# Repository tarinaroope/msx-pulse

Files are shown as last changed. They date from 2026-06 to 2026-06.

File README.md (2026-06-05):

# msx-pulse

A diagnostic cartridge for MSX computers. Very much a work in progress. This is at
proof-of-concept stage. It boots, it reads the bus, it tells you things, but it's a
long way from a finished product. I'm building it partly because I wanted an "is this
MSX dead, and if so why" tool, and partly to learn, so expect rough edges.

## What it does today

Plug it into the cartridge slot and it sits there passively. It doesn't drive the bus,
so it's safe to leave in while the MSX powers up on its own. While it watches, it
reports on a small OLED:

- the +5V, +12V and −12V rails
- whether the 3.58 MHz clock is alive and roughly the right frequency
- the state of /RESET
- what the address and data lines are doing, including bits that look stuck or are
  never driven

It can also pulse /RESET and follow the early boot sequence to see how far the machine
gets. There's a USB serial log too if you want the detail on a host.

That's already enough to tell, say, a dead clock apart from dead RAM without pulling
the machine apart. I'm still working out the full list of faults it can sensibly
diagnose and a lot of that will come from pointing it at actually-broken machines and
seeing what shows up.

## What's next

The next goal is to have the cartridge *serve* a diagnostic ROM to the MSX and act as
the boot ROM itself and run Z80 test code on the machine's own CPU, the way the Dead
Test cart does. The firmware already has the groundwork for this (it can emulate a ROM
on the bus), but turning that into a proper guided test sequence is the next chunk of
work. The passive monitoring above is the part that somewhat works.

## Hardware

Fair warning: I'm a software person, not a hardware engineer, and this board is one of
the first things I've designed. It's a quick first cut to get *something* I could test
firmware against, and it shows. There's a KiCad project in [`hardware/`](hardware/)
(schematics, PCB, gerbers) and a parts list in [`docs/BOM.csv`](docs/BOM.csv) — read
them as "what I actually had made", not "the right way to do this".

The brain is a bare RP2354B (the QFN-80 part, 48 GPIO, 2 MB internal flash) wired onto
the cartridge edge connector and powered from the slot. The current board puts 74LVC245
level shifters on just about every bus line. Having lived with it, I think that's
overkill... the address and control inputs could most likely get by with plain series
resistors and no shifters. The data lines are the exception: those are bidirectional
and actually get driven, so keeping real level shifting there still makes sense, mostly
for protection.

Things I'd like to change in the next board revision:

- drop the level shifters on the address/control inputs, keep them on D0–D7
- shrink the PCB to fit an actual MSX cartridge shell (it's oversized right now)
- swap the ADC protection diodes as I miscalculated the zeners, seems it works even better without.
- a bigger power-on-reset cap for a more reliable cold boot
- a normal 2.54 mm SWD header (plus a UART header which I omitted) instead of the fine-pitch one I used

## Building

You'll need the Arm GNU toolchain (`arm-none-eabi`), the Raspberry Pi Pico SDK, and
sjasmplus for the Z80 side.

```sh
export PICO_SDK_PATH=/path/to/pico-sdk
cmake -S . -B build -DPICO_TOOLCHAIN_PATH=/path/to/arm-none-eabi/bin
cmake --build build -j
```

Out comes:

- `build/src/firmware/msxdoc.uf2` — the firmware
- `build/diag.rom` — the Z80 test ROM, assembled and baked into the firmware for you (not served) 

## Flashing

Hold BOOTSEL, plug into USB, and drop the `.uf2` onto the drive that appears. Or, with
picotool:

```sh
picotool load -x build/src/firmware/msxdoc.uf2
```

Or via swd.

## Layout

```
src/rom/        Z80 test ROM (sjasmplus)
src/firmware/   RP2354B firmware (pico-sdk, C + PIO)
hardware/       KiCad schematics, PCB, gerbers
docs/           bill of materials
```

## License

MIT — see [LICENSE](LICENSE).

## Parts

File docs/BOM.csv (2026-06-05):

Designator | Qty | Value | Package | Description | MPN / Note | LCSC Part #
U2 | 1 | RP2354B | QFN-80 | MCU — ROM emulator, bus monitor, output controller | Raspberry Pi RP2354B
U1 | 1 | AP2112K-3.3 | SOT-23-5 | LDO 600mA, 3.3V fixed output | Diodes AP2112K-3.3TRG1
U3, U4, U5, U6 | 4 | 74LVC245 | SOIC-20 | Octal bus transceiver, 5V tolerant, 3.3V VCC | TI SN74LVC245ADWR or equiv
L1 | 1 | 3.3µH, Abracon AOTA-B201610S3R3-101-T | 0806 (2016 metric) | SMPS inductor — polarity dot CRITICAL; use this exact part | Abracon AOTA-B201610S3R3-101-T
D1 | 1 | BAT54C | SOT-23 | Dual Schottky, common cathode — power OR circuit | Nexperia BAT54C,215
D2, D3, D4 | 3 | BZX84-C3V3 | SOT-23 | 3.3V Zener — ADC input overvoltage clamp. [SPIN-2: replace with PESD3V3L1BA SOT-23, see KNOWN_RISKS L7] | Nexperia BZX84-C3V3,235 or equiv
Q1 | 1 | 2N7002 | SOT-23 | N-MOSFET — MSX /RESET drive | Nexperia 2N7002,235 or equiv
Y1 | 1 | 12MHz crystal | 3225 SMD | Crystal — USB and PIO timing; ABM8-272-T3 recommended | Abracon ABM8-272-T3 (recommended) or equiv 12MHz 10pF 50Ω ESR
R20, R22 | 2 | 27Ω | 0603 5% | USB DP/DM series termination — place close to MCU
R3, R14, R24 | 3 | 33Ω | 0603 5% | 2N7002 gate damper (R3) + VREG_AVDD filter (R14) + ADC_AVDD filter (R24)
R4, R23 | 2 | 330Ω | 0603 5% | LED current limiter (R4), /WAIT series protection (R23)
R9, R15, R18, R19, R21 | 5 | 1kΩ | 0603 5% | BOOTSEL isolation, crystal XOUT damping, ADC series protection
R1, R2 | 2 | 10kΩ | 0603 5% | RUN pin pull-up (R1) + 74LVC245 /OE pull-up (R2)
R5, R6 | 2 | 4.7kΩ | 0603 5% | I2C SDA + SCL pull-ups
R7, R8 | 2 | 5.1kΩ | 0603 5% | USB-C CC1 + CC2 pull-downs
R10, R11, R13, R16 | 4 | 10kΩ | 0603 1% | ADC voltage dividers (1% required for rail measurement accuracy)
R12 | 1 | 33kΩ | 0603 1% | +12V rail divider (high side)
R17 | 1 | 82kΩ | 0603 1% | −12V bridge divider (low side)
C4, C5 | 2 | 15pF C0G/NP0 | 0603 | Crystal load caps — C0G/NP0 mandatory
C1 | 1 | 1µF X5R 6.3V | 0603 | LDO VIN bypass
C2 | 1 | 10µF X5R 6.3V | 0603 | LDO output bulk cap
C24 | 1 | 1µF X5R 6.3V | 0402 | ADC_AVDD filter cap
C18, C19, C20 | 3 | 4.7µF X5R 6.3V | 0402 | VREG: AVDD filter cap (C18), VIN bypass (C19), DVDD output (C20)
C3, C6 | 2 | 100nF X7R 10V | 0603 | Decoupling: LDO local (C3), reset RC (C6)
C7, C8, C9, C10, C11, C12, C13, C14, C15, C16, C21, C22, C23 | 13 | 100nF X7R 10V | 0402 | MCU decoupling: IOVDD (×8, C7–C14), QSPI/USB (×2, C15–C16), DVDD (×3, C21–C23)
J3 | 1 | GCT USB4085 | mid-mount SMD | USB-C receptacle — firmware update + serial log | GCT USB4085-GF-A
J4 | 1 | SWD 3-pin header | 1.27mm pitch SMD | SWD debug: SWDIO / SWDCLK / GND
J2 | 1 | 4-pin 2.54mm header | through-hole | OLED mounting header (SDA, SCL, GND, 3.3V)
SW1, SW2, SW3, SW4 | 4 | 6×6mm SMD tactile | SMD | Buttons: RESET (SW1), UP (SW2), DOWN (SW3), SELECT (SW4) | C&K PTS645SK43SMTR92 LFS or equiv
LED1 | 1 | Green LED | 0603 | Firmware-driven status LED (GP38 via R4). Not a passive power indicator.

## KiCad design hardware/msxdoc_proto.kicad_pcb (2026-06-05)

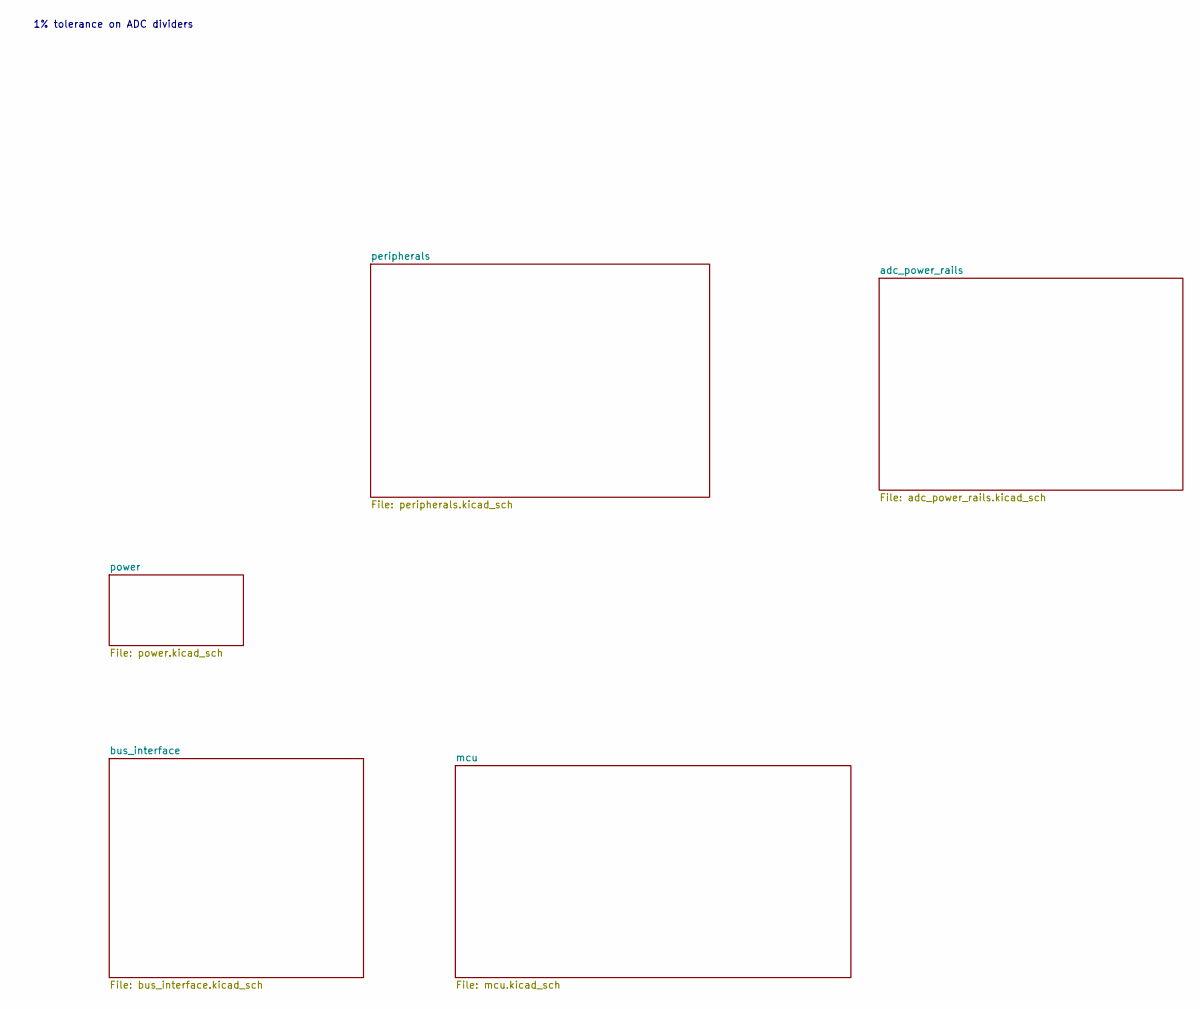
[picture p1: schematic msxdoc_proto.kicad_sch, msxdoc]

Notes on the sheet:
1% tolerance on ADC dividers

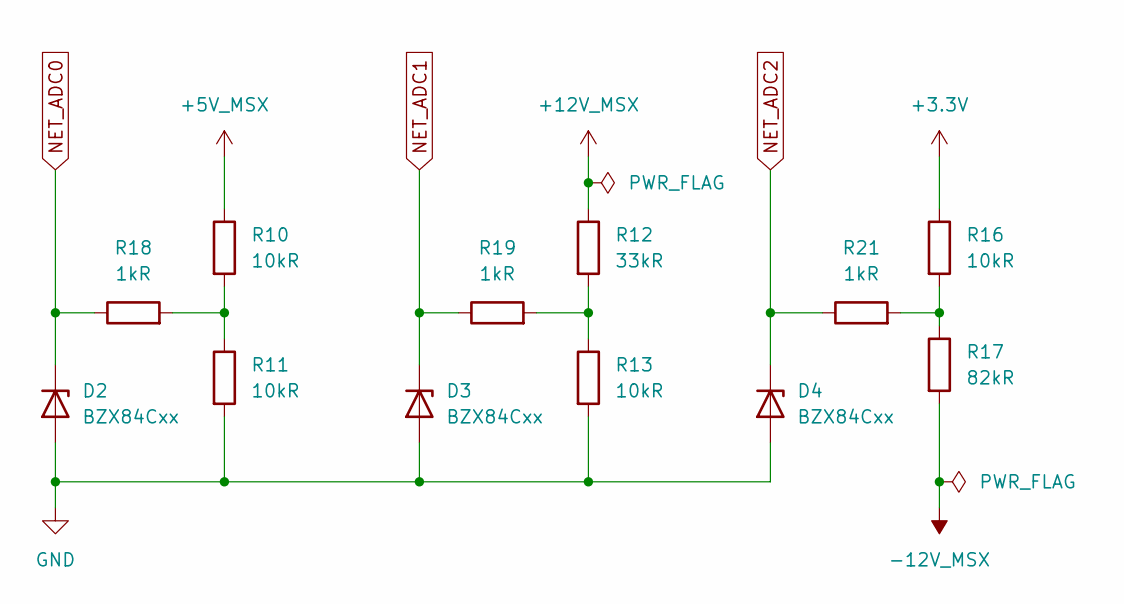
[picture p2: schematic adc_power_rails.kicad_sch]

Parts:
D2, D3, D4: BZX84Cxx; SOT-23
R10, R11, R13, R16: 10kR; R_0603_1608Metric
R12: 33kR; R_0603_1608Metric
R17: 82kR; R_0603_1608Metric
R18, R19, R21: 1kR; R_0603_1608Metric

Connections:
+3.3V: R16.1; also elsewhere on the board
+5V_MSX: R10.1; also elsewhere on the board
+12V_MSX: R12.1; also elsewhere on the board
-12V_MSX: R17.2; also elsewhere on the board
GND: D2.1 (A), D3.1 (A), D4.1 (A), R11.2, R13.2; also elsewhere on the board
NET_ADC0: D2.3 (K), R18.1; also elsewhere on the board
NET_ADC1: D3.3 (K), R19.1; also elsewhere on the board
NET_ADC2: D4.3 (K), R21.1; also elsewhere on the board
unnamed: R10.2, R11.1, R18.2
unnamed: R12.2, R13.1, R19.2
unnamed: R16.2, R17.1, R21.2

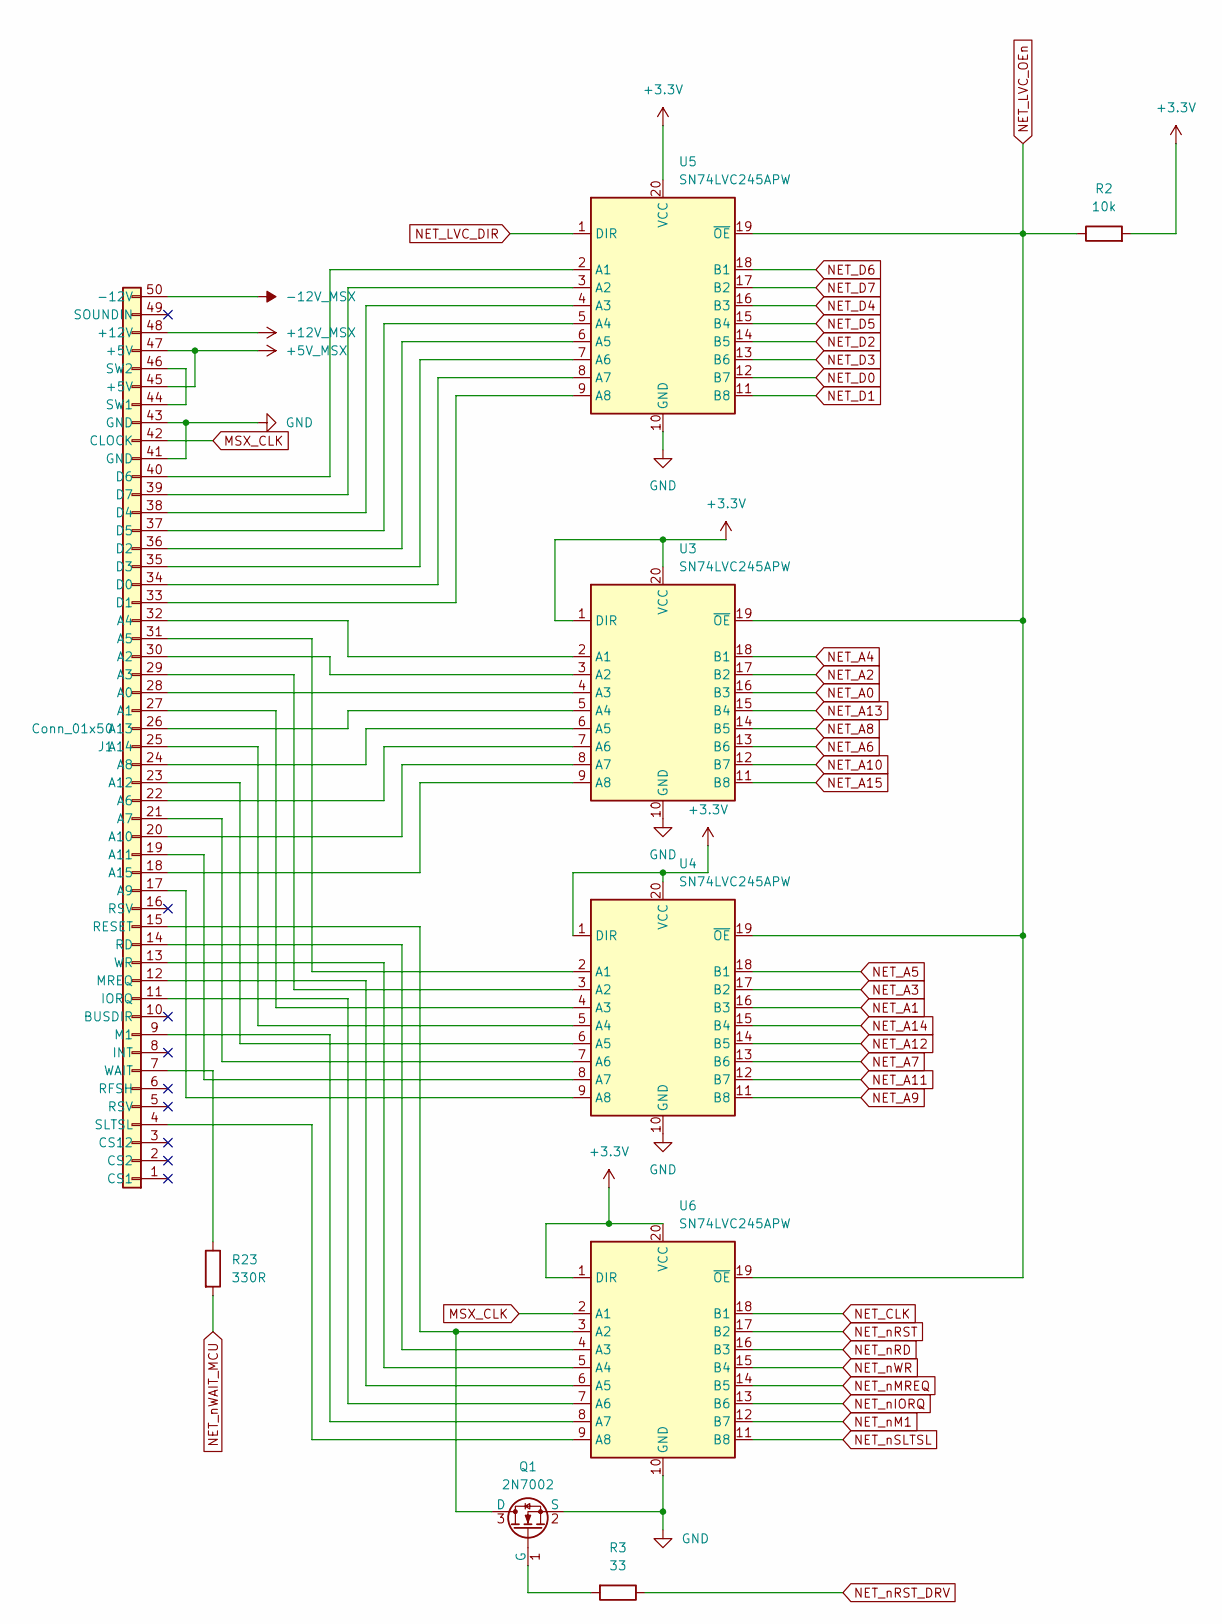
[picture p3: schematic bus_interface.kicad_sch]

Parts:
J1: Conn_01x50; MSX-EDGE
Q1: 2N7002; SOT-23; LCSC C81445
R2: 10k; R_0603_1608Metric
R3: 33; R_0603_1608Metric
R23: 330R; R_0603_1608Metric
U3, U4, U5, U6: SN74LVC245APW; TSSOP-20_4.4x6.5mm_P0.65mm; LCSC C7848

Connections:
+3.3V: R2.2, U3.1 (DIR), U3.20 (VCC), U4.1 (DIR), U4.20 (VCC), U5.20 (VCC), U6.1 (DIR), U6.20 (VCC); also elsewhere on the board
+5V_MSX: J1.45 (+5V), J1.47 (+5V); also elsewhere on the board
+12V_MSX: J1.48 (+12V); also elsewhere on the board
-12V_MSX: J1.50 (-12V); also elsewhere on the board
GND: J1.41 (GND), J1.43 (GND), Q1.2 (S), U3.10 (GND), U4.10 (GND), U5.10 (GND), U6.10 (GND); also elsewhere on the board
MSX_CLK: J1.42 (CLOCK), U6.2 (A1)
NET_A0: U3.16 (B3); also elsewhere on the board
NET_A1: U4.16 (B3); also elsewhere on the board
NET_A2: U3.17 (B2); also elsewhere on the board
NET_A3: U4.17 (B2); also elsewhere on the board
NET_A4: U3.18 (B1); also elsewhere on the board
NET_A5: U4.18 (B1); also elsewhere on the board
NET_A6: U3.13 (B6); also elsewhere on the board
NET_A7: U4.13 (B6); also elsewhere on the board
NET_A8: U3.14 (B5); also elsewhere on the board
NET_A9: U4.11 (B8); also elsewhere on the board
NET_A10: U3.12 (B7); also elsewhere on the board
NET_A11: U4.12 (B7); also elsewhere on the board
NET_A12: U4.14 (B5); also elsewhere on the board
NET_A13: U3.15 (B4); also elsewhere on the board
NET_A14: U4.15 (B4); also elsewhere on the board
NET_A15: U3.11 (B8); also elsewhere on the board
NET_CLK: U6.18 (B1); also elsewhere on the board
NET_D0: U5.12 (B7); also elsewhere on the board
NET_D1: U5.11 (B8); also elsewhere on the board
NET_D2: U5.14 (B5); also elsewhere on the board
NET_D3: U5.13 (B6); also elsewhere on the board
NET_D4: U5.16 (B3); also elsewhere on the board
NET_D5: U5.15 (B4); also elsewhere on the board
NET_D6: U5.18 (B1); also elsewhere on the board
NET_D7: U5.17 (B2); also elsewhere on the board
NET_LVC_DIR: U5.1 (DIR); also elsewhere on the board
NET_LVC_OEn: R2.1, U3.19 (~OE), U4.19 (~OE), U5.19 (~OE), U6.19 (~OE); also elsewhere on the board
NET_nIORQ: U6.13 (B6); also elsewhere on the board
NET_nM1: U6.12 (B7); also elsewhere on the board
NET_nMREQ: U6.14 (B5); also elsewhere on the board
NET_nRD: U6.16 (B3); also elsewhere on the board
NET_nRST: U6.17 (B2); also elsewhere on the board
NET_nRST_DRV: R3.1; also elsewhere on the board
NET_nSLTSL: U6.11 (B8); also elsewhere on the board
NET_nWAIT_MCU: R23.2; also elsewhere on the board
NET_nWR: U6.15 (B4); also elsewhere on the board
unnamed: J1.28 (A0), U3.4 (A3)
unnamed: J1.27 (A1), U4.4 (A3)
unnamed: J1.30 (A2), U3.3 (A2)
unnamed: J1.29 (A3), U4.3 (A2)
unnamed: J1.32 (A4), U3.2 (A1)
unnamed: J1.31 (A5), U4.2 (A1)
unnamed: J1.22 (A6), U3.7 (A6)
unnamed: J1.21 (A7), U4.7 (A6)
unnamed: J1.24 (A8), U3.6 (A5)
unnamed: J1.17 (A9), U4.9 (A8)
unnamed: J1.20 (A10), U3.8 (A7)
unnamed: J1.19 (A11), U4.8 (A7)
unnamed: J1.23 (A12), U4.6 (A5)
unnamed: J1.26 (A13), U3.5 (A4)
unnamed: J1.25 (A14), U4.5 (A4)
unnamed: J1.18 (A15), U3.9 (A8)
unnamed: J1.34 (D0), U5.8 (A7)
unnamed: J1.33 (D1), U5.9 (A8)
unnamed: J1.36 (D2), U5.6 (A5)
unnamed: J1.35 (D3), U5.7 (A6)
unnamed: J1.38 (D4), U5.4 (A3)
unnamed: J1.37 (D5), U5.5 (A4)
unnamed: J1.40 (D6), U5.2 (A1)
unnamed: J1.39 (D7), U5.3 (A2)
unnamed: J1.11 (IORQ), U6.7 (A6)
unnamed: J1.9 (M1), U6.8 (A7)
unnamed: J1.12 (MREQ), U6.6 (A5)
unnamed: J1.14 (RD), U6.4 (A3)
unnamed: J1.15 (RESET), Q1.3 (D), U6.3 (A2)
unnamed: J1.4 (SLTSL), U6.9 (A8)
unnamed: J1.44 (SW1), J1.46 (SW2)
unnamed: J1.7 (WAIT), R23.1
unnamed: J1.13 (WR), U6.5 (A4)
unnamed: Q1.1 (G), R3.2

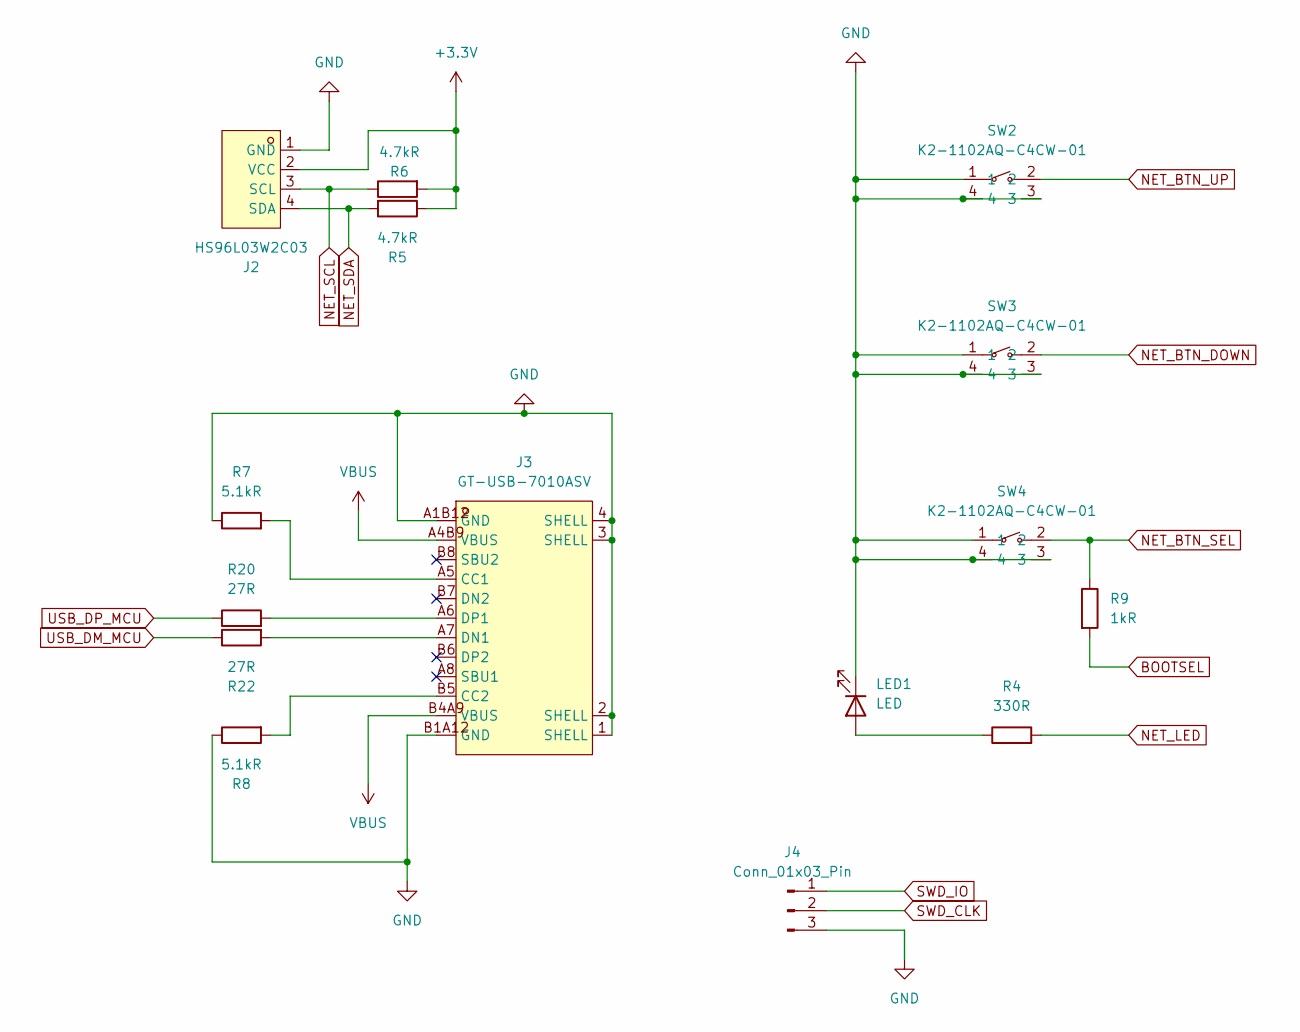
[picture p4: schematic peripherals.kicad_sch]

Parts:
J2: HS96L03W2C03; OLED-TH_L27.8-W27.2-P2.54_C9900033791; MPN HS96L03W2C03; LCSC Part C5248080
J3: GT-USB-7010ASV; USB-C-SMD_G-SWITCH_GT-USB-7010ASV; MPN GT-USB-7010ASV; LCSC Part C2988369
J4: Conn_01x03_Pin; PinHeader_1x03_P2.54mm_Vertical
LED1: LED; LED_0603_1608Metric
R4: 330R; R_0603_1608Metric
R5, R6: 4.7kR; R_0603_1608Metric
R7, R8: 5.1kR; R_0603_1608Metric
R9: 1kR; R_0603_1608Metric
R20, R22: 27R; R_0603_1608Metric
SW2, SW3, SW4: K2-1102AQ-C4CW-01; SW-TH_K2-1102AQ-C4CW-01; MPN K2-1102AQ-C4CW-01; LCSC Part C127680

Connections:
+3.3V: J2.2 (VCC), R5.1, R6.2; also elsewhere on the board
BOOTSEL: R9.2; also elsewhere on the board
GND: J2.1 (GND), J3.1 (SHELL), J3.2 (SHELL), J3.3 (SHELL), J3.4 (SHELL), J3.A1B12 (GND), J3.B1A12 (GND), J4.3, LED1.1 (K), R7.1, R8.1, SW2.1, SW2.3, SW2.4, SW3.1, SW3.3, SW3.4, SW4.1, SW4.3, SW4.4; also elsewhere on the board
NET_BTN_DOWN: SW3.2; also elsewhere on the board
NET_BTN_SEL: R9.1, SW4.2; also elsewhere on the board
NET_BTN_UP: SW2.2; also elsewhere on the board
NET_LED: R4.2; also elsewhere on the board
NET_SCL: J2.3 (SCL), R6.1; also elsewhere on the board
NET_SDA: J2.4 (SDA), R5.2; also elsewhere on the board
unnamed: J3.A5 (CC1), R7.2
unnamed: J3.B5 (CC2), R8.2
unnamed: J3.A7 (DN1), R22.2
unnamed: J3.A6 (DP1), R20.2
unnamed: LED1.2 (A), R4.1
SWD_CLK: J4.2; also elsewhere on the board
SWD_IO: J4.1; also elsewhere on the board
USB_DM_MCU: R22.1; also elsewhere on the board
USB_DP_MCU: R20.1; also elsewhere on the board
VBUS: J3.A4B9 (VBUS), J3.B4A9 (VBUS); also elsewhere on the board

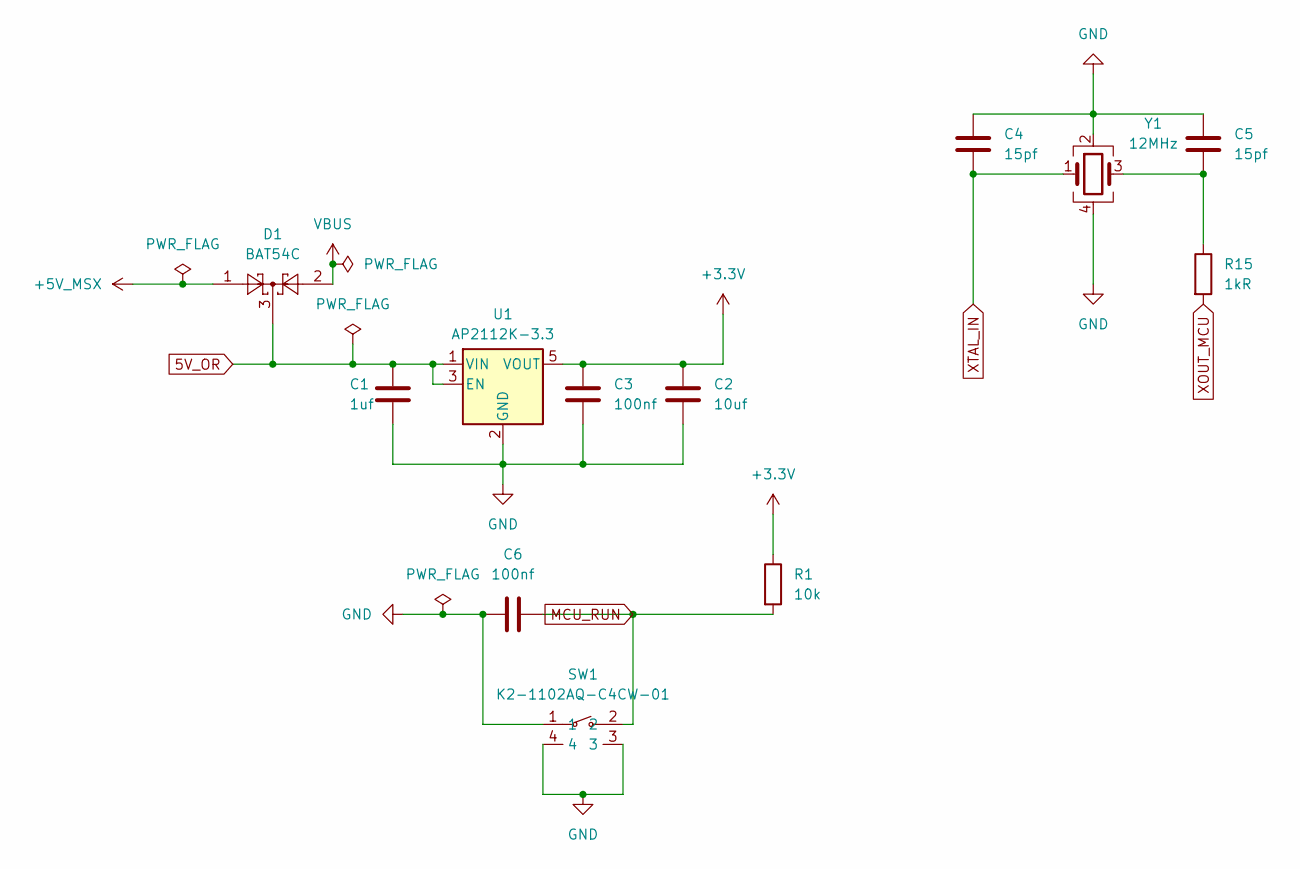
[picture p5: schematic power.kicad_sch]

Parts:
C1: 1uf; C_0603_1608Metric
C2: 10uf; C_0603_1608Metric
C3, C6: 100nf; C_0603_1608Metric
C4, C5: 15pf; C_0603_1608Metric
D1: BAT54C; SOT-23; LCSC C37704
R1: 10k; R_0603_1608Metric
R15: 1kR; R_0603_1608Metric
SW1: K2-1102AQ-C4CW-01; SW-TH_K2-1102AQ-C4CW-01; MPN K2-1102AQ-C4CW-01; LCSC Part C127680
U1: AP2112K-3.3; SOT-23-5; LCSC C23380830
Y1: 12MHz; Crystal_SMD_3225-4Pin_3.2x2.5mm; LCSC part C20625731

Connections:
5V_OR: C1.1, D1.3, U1.1 (VIN), U1.3 (EN)
+3.3V: C2.1, C3.1, R1.1, U1.5 (VOUT); also elsewhere on the board
+5V_MSX: D1.1; also elsewhere on the board
GND: C1.2, C2.2, C3.2, C4.1, C5.1, C6.1, SW1.1, SW1.3, SW1.4, U1.2 (GND), Y1.2, Y1.4; also elsewhere on the board
MCU_RUN: C6.2, R1.2, SW1.2; also elsewhere on the board
unnamed: C5.2, R15.1, Y1.3
VBUS: D1.2; also elsewhere on the board
XOUT_MCU: R15.2; also elsewhere on the board
XTAL_IN: C4.2, Y1.1; also elsewhere on the board

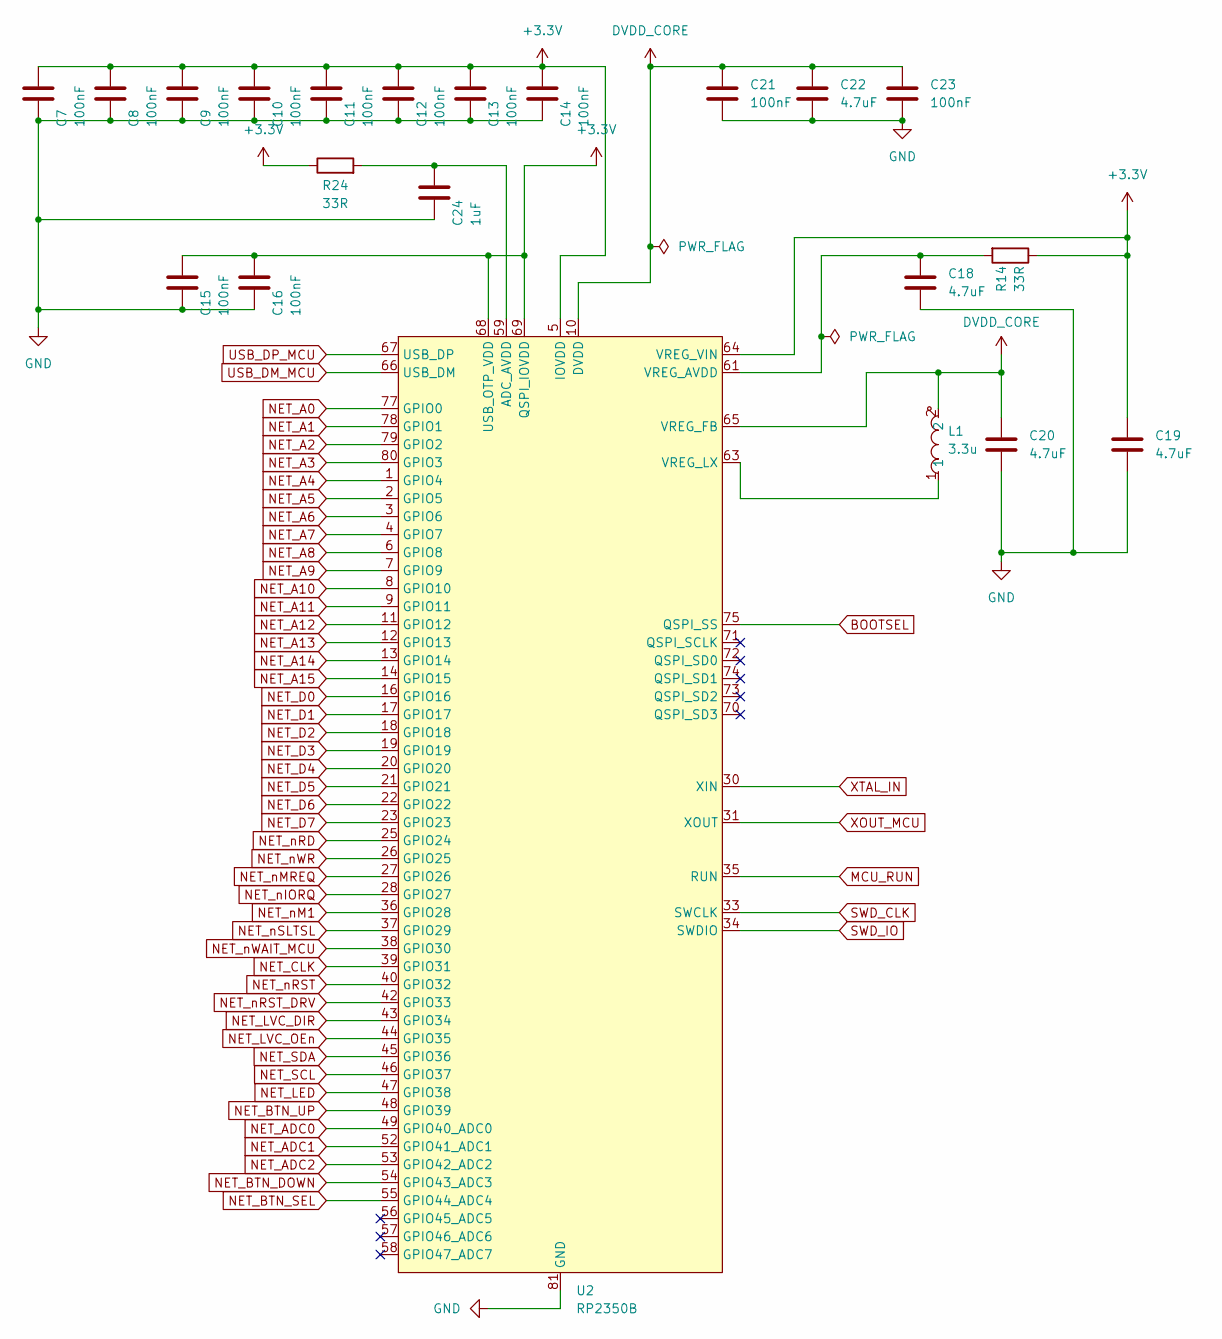
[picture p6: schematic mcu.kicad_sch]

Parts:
C7, C8, C9, C10, C11, C12, C13, C14, C15, C16, C21, C23: 100nF; C_0402_1005Metric
C18, C19, C20, C22: 4.7uF; C_0402_1005Metric
C24: 1uF; C_0402_1005Metric
L1: 3.3u; IND-SMD_L2.0-W1.6_AOTA-B201610S3R3-101-T; MPN AOTA-B201610S3R3-101-T; LCSC Part C42411119
R14, R24: 33R; R_0603_1608Metric
U2: RP2350B; QFN-80-1EP_10x10mm_P0.4mm_EP3.4x3.4mm_ThermalVias

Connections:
+3.3V: C7.1, C8.1, C9.1, C10.1, C11.1, C12.1, C13.1, C14.1, C15.1, C16.1, C19.1, R14.1, R24.1, U2.5 (IOVDD), U2.15 (IOVDD), U2.24 (IOVDD), U2.29 (IOVDD), U2.41 (IOVDD), U2.50 (IOVDD), U2.60 (IOVDD), U2.64 (VREG_VIN), U2.68 (USB_OTP_VDD), U2.69 (QSPI_IOVDD), U2.76 (IOVDD); also elsewhere on the board
BOOTSEL: U2.75 (QSPI_SS); also elsewhere on the board
DVDD_CORE: C20.1, C21.1, C22.1, C23.1, L1.2, U2.10 (DVDD), U2.32 (DVDD), U2.51 (DVDD), U2.65 (VREG_FB)
GND: C7.2, C8.2, C9.2, C10.2, C11.2, C12.2, C13.2, C14.2, C15.2, C16.2, C18.2, C19.2, C20.2, C21.2, C22.2, C23.2, C24.2, U2.62 (VREG_PGND), U2.81 (GND); also elsewhere on the board
MCU_RUN: U2.35 (RUN); also elsewhere on the board
NET_A0: U2.77 (GPIO0); also elsewhere on the board
NET_A1: U2.78 (GPIO1); also elsewhere on the board
NET_A2: U2.79 (GPIO2); also elsewhere on the board
NET_A3: U2.80 (GPIO3); also elsewhere on the board
NET_A4: U2.1 (GPIO4); also elsewhere on the board
NET_A5: U2.2 (GPIO5); also elsewhere on the board
NET_A6: U2.3 (GPIO6); also elsewhere on the board
NET_A7: U2.4 (GPIO7); also elsewhere on the board
NET_A8: U2.6 (GPIO8); also elsewhere on the board
NET_A9: U2.7 (GPIO9); also elsewhere on the board
NET_A10: U2.8 (GPIO10); also elsewhere on the board
NET_A11: U2.9 (GPIO11); also elsewhere on the board
NET_A12: U2.11 (GPIO12); also elsewhere on the board
NET_A13: U2.12 (GPIO13); also elsewhere on the board
NET_A14: U2.13 (GPIO14); also elsewhere on the board
NET_A15: U2.14 (GPIO15); also elsewhere on the board
NET_ADC0: U2.49 (GPIO40_ADC0); also elsewhere on the board
NET_ADC1: U2.52 (GPIO41_ADC1); also elsewhere on the board
NET_ADC2: U2.53 (GPIO42_ADC2); also elsewhere on the board
NET_BTN_DOWN: U2.54 (GPIO43_ADC3); also elsewhere on the board
NET_BTN_SEL: U2.55 (GPIO44_ADC4); also elsewhere on the board
NET_BTN_UP: U2.48 (GPIO39); also elsewhere on the board
NET_CLK: U2.39 (GPIO31); also elsewhere on the board
NET_D0: U2.16 (GPIO16); also elsewhere on the board
NET_D1: U2.17 (GPIO17); also elsewhere on the board
NET_D2: U2.18 (GPIO18); also elsewhere on the board
NET_D3: U2.19 (GPIO19); also elsewhere on the board
NET_D4: U2.20 (GPIO20); also elsewhere on the board
NET_D5: U2.21 (GPIO21); also elsewhere on the board
NET_D6: U2.22 (GPIO22); also elsewhere on the board
NET_D7: U2.23 (GPIO23); also elsewhere on the board
NET_LED: U2.47 (GPIO38); also elsewhere on the board
NET_LVC_DIR: U2.43 (GPIO34); also elsewhere on the board
NET_LVC_OEn: U2.44 (GPIO35); also elsewhere on the board
NET_SCL: U2.46 (GPIO37); also elsewhere on the board
NET_SDA: U2.45 (GPIO36); also elsewhere on the board
NET_nIORQ: U2.28 (GPIO27); also elsewhere on the board
NET_nM1: U2.36 (GPIO28); also elsewhere on the board
NET_nMREQ: U2.27 (GPIO26); also elsewhere on the board
NET_nRD: U2.25 (GPIO24); also elsewhere on the board
NET_nRST: U2.40 (GPIO32); also elsewhere on the board
NET_nRST_DRV: U2.42 (GPIO33); also elsewhere on the board
NET_nSLTSL: U2.37 (GPIO29); also elsewhere on the board
NET_nWAIT_MCU: U2.38 (GPIO30); also elsewhere on the board
NET_nWR: U2.26 (GPIO25); also elsewhere on the board
unnamed: C24.1, R24.2, U2.59 (ADC_AVDD)
unnamed: C18.1, R14.2, U2.61 (VREG_AVDD)
unnamed: L1.1, U2.63 (VREG_LX)
SWD_CLK: U2.33 (SWCLK); also elsewhere on the board
SWD_IO: U2.34 (SWDIO); also elsewhere on the board
USB_DM_MCU: U2.66 (USB_DM); also elsewhere on the board
USB_DP_MCU: U2.67 (USB_DP); also elsewhere on the board
XOUT_MCU: U2.31 (XOUT); also elsewhere on the board
XTAL_IN: U2.30 (XIN); also elsewhere on the board

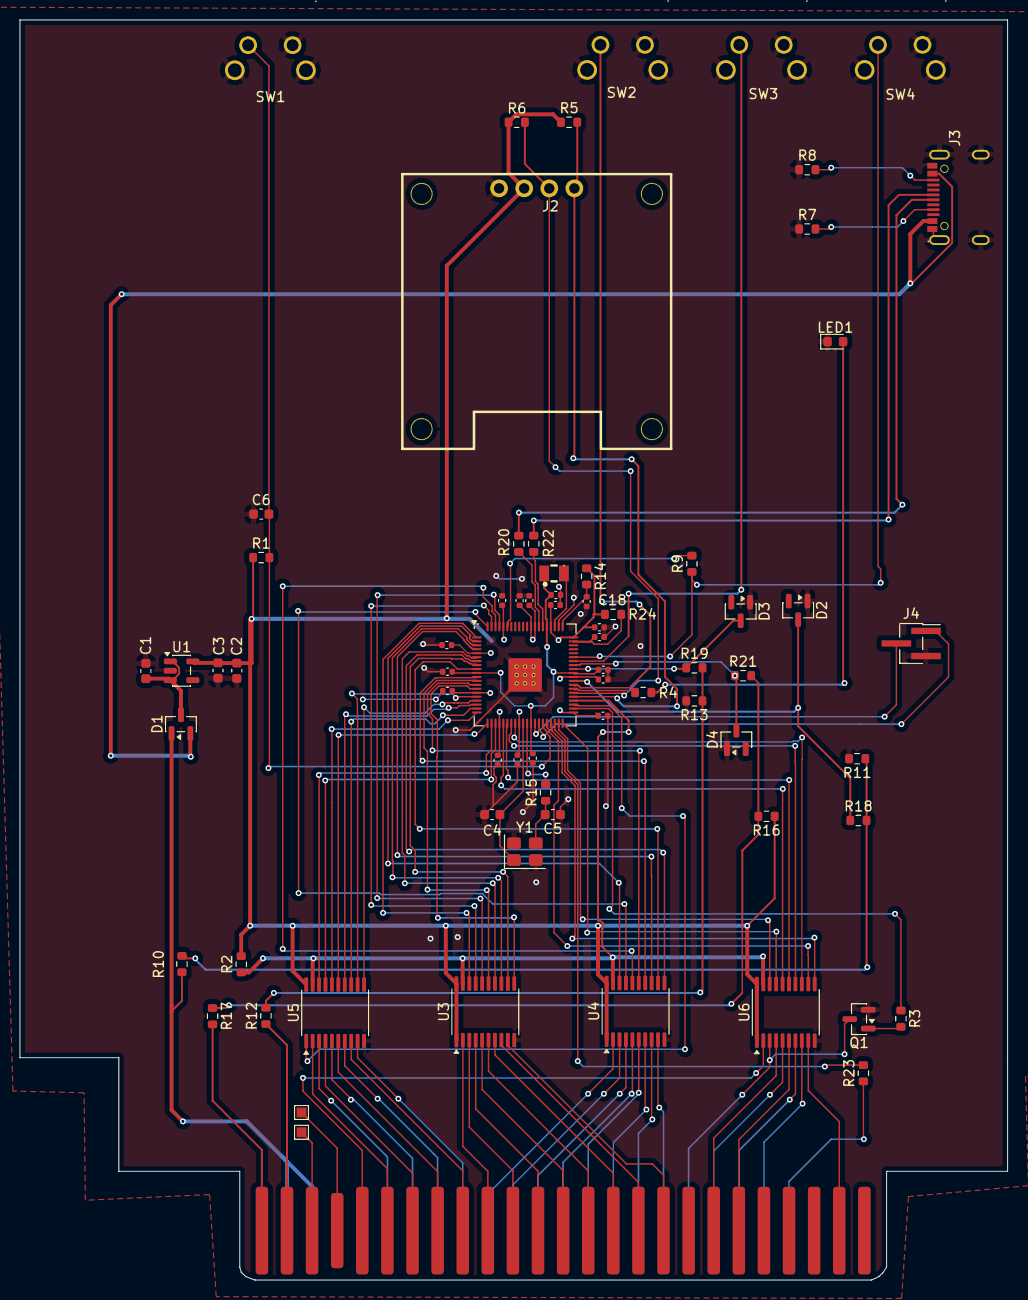
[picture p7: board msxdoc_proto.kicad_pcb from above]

Board: 2 copper layers, 99.9 x 127.5 mm, 69 parts (0 on the bottom side), 108 nets.

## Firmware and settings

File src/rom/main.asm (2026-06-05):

    DEVICE NOSLOT64K
    ORG $4000

VDP_DATA    EQU $98
VDP_CTRL    EQU $99

PSG_ADDR    EQU $A0     ; write: latch register number
PSG_DATA    EQU $A1     ; write: write to latched register
PSG_READ    EQU $A2     ; read:  read from latched register

SLOT_REG    EQU $A8     ; primary slot select register
KB_COLRD    EQU $A9     ; PPI port B: keyboard column read
KB_ROWSEL   EQU $AA     ; PPI port C: keyboard row select (bits 3:0)

VRAM_NAME   EQU $0000       ; Screen 0 name table (40×24)
VRAM_PTRN   EQU $0800       ; Screen 0 pattern table (256 × 8 bytes)
COLS        EQU 40

RAM_START   EQU $C000       ; first byte of guaranteed MSX1 main RAM
RAM_END     EQU $FFFF       ; last byte

VRAM_TEST_START EQU $1000   ; first VRAM byte safe to test (avoids display area)
VRAM_TEST_END   EQU $3FFF   ; last VRAM byte (12 KB)

    DB  "AB"            ; $4000  cartridge ID
    DW  Init            ; $4002  INIT entry point
    DW  0               ; $4004  STATEMENT (unused)
    DW  0               ; $4006  DEVICE    (unused)
    DW  0               ; $4008  TEXT      (unused)
    DS  6, 0            ; $400A  reserved

Init:
    DI
    ld  sp, $FFFF       ; stack at top of RAM before any testing

    ; Init the VDP directly instead of via BIOS CHGMOD ($005F), so the
    ; diagnostic still shows output if the main BIOS ROM is dead. Sets up
    ; Screen 0 (text, 40x24), loads the font into the pattern table, clears
    ; the name table.
    in  a, (VDP_CTRL)   ; sync VDP byte flip-flop before writes

    ld  a, $00          ; R0: M3=0, no external video, no hsync int
    ld  e, 0
    call VDP_WriteReg
    ld  a, $D0          ; R1: display ON, M1=1 (Text Mode), no frame int
    ld  e, 1
    call VDP_WriteReg
    ld  a, $00          ; R2: name table base = VRAM $0000
    ld  e, 2
    call VDP_WriteReg
    ld  a, $01          ; R4: pattern table base = VRAM $0800
    ld  e, 4
    call VDP_WriteReg
    ld  a, $F4          ; R7: text = white ($F), bg = dark blue ($4)
    ld  e, 7
    call VDP_WriteReg

    call LoadFont       ; copy 96 printable-ASCII glyphs to VRAM $0900+

    call ClearScreen

    ld  hl, Str_Banner
    ld  de, VRAM_NAME + COLS * 1 + 11   ; row 1, centred
    call PrintStr

    ; CPU register / ALU test
    ld  hl, Str_CpuLabel
    ld  de, VRAM_NAME + COLS * 3 + 2
    call PrintStr

    call TestCPU
    ld  hl, Str_Pass
    or  a
    jr  z, .cpu_done
    ld  hl, Str_Fail
.cpu_done:
    ld  de, VRAM_NAME + COLS * 3 + 22
    call PrintStr

    ; RAM test ($C000-$FFFF, 16 KB).
    ; The test loops use only LD/INC/DEC/JP, no CALL, so the stack at $FFFF
    ; stays untouched while testing. CALLs before and after are fine. If the
    ; stack bytes ($FFFD-$FFFE) are themselves bad, a post-test CALL crashes —
    ; accepted, since the fault was already detected.
    ld  hl, Str_RamLabel
    ld  de, VRAM_NAME + COLS * 5 + 2
    call PrintStr

    ; Pass 1: write $AA
    ld  d, $AA
    ld  hl, RAM_START
    ld  bc, RAM_END - RAM_START + 1
.ram_w1:
    ld  (hl), $AA
    inc hl
    dec bc
    ld  a, b
    or  c
    jr  nz, .ram_w1

    ; Pass 1: verify $AA
    ld  hl, RAM_START
    ld  bc, RAM_END - RAM_START + 1
.ram_r1:
    ld  a, (hl)
    cp  d
    jp  nz, .ram_fail
    inc hl
    dec bc
    ld  a, b
    or  c
    jr  nz, .ram_r1

    ; Pass 2: write $55
    ld  d, $55
    ld  hl, RAM_START
    ld  bc, RAM_END - RAM_START + 1
.ram_w2:
    ld  (hl), $55
    inc hl
    dec bc
    ld  a, b
    or  c
    jr  nz, .ram_w2

    ; Pass 2: verify $55
    ld  hl, RAM_START
    ld  bc, RAM_END - RAM_START + 1
.ram_r2:
    ld  a, (hl)
    cp  d
    jp  nz, .ram_fail
    inc hl
    dec bc
    ld  a, b
    or  c
    jr  nz, .ram_r2

.ram_pass:
    ld  hl, Str_Pass
    ld  de, VRAM_NAME + COLS * 5 + 22
    call PrintStr
    jr  .ram_done

.ram_fail:
    ; On entry: HL = failing address, D = expected, A = actual value read
    ld  e, a            ; save actual before A gets clobbered

    push hl
    push de
    ld  hl, Str_Fail
    ld  de, VRAM_NAME + COLS * 5 + 22
    call PrintStr
    pop  de
    pop  hl             ; HL = fail addr, D = expected, E = actual

    ; Detail line: "  $XXXX exp:$XX got:$XX"
    push de
    push hl
    ld  hl, VRAM_NAME + COLS * 6 + 2
    call VDP_SetWrite
    pop  hl
    pop  de

    ld  a, ' '
    out (VDP_DATA), a
    out (VDP_DATA), a
    ld  a, '$'
    out (VDP_DATA), a
    call PrintHex16     ; HL = fail address (preserved by PrintHex16)

    ld  a, ' '
    out (VDP_DATA), a
    ld  a, 'e'
    out (VDP_DATA), a
    ld  a, 'x'
    out (VDP_DATA), a
    ld  a, 'p'
    out (VDP_DATA), a
    ld  a, ':'
    out (VDP_DATA), a
    ld  a, '$'
    out (VDP_DATA), a
    ld  a, d
    call PrintHex8

    ld  a, ' '
    out (VDP_DATA), a
    ld  a, 'g'
    out (VDP_DATA), a
    ld  a, 'o'
    out (VDP_DATA), a
    ld  a, 't'
    out (VDP_DATA), a
    ld  a, ':'
    out (VDP_DATA), a
    ld  a, '$'
    out (VDP_DATA), a
    ld  a, e
    call PrintHex8

.ram_done:

    ; VRAM test ($1000-$3FFF, 12 KB)
    ld  hl, Str_VramLabel
    ld  de, VRAM_NAME + COLS * 7 + 2
    call PrintStr

    ; Pass 1: write $AA
    ld  hl, VRAM_TEST_START
    call VDP_SetWrite
    ld  bc, VRAM_TEST_END - VRAM_TEST_START + 1
.vram_w1:
    ld  a, $AA
    out (VDP_DATA), a
    dec bc
    ld  a, b
    or  c
    jr  nz, .vram_w1

    ; Pass 1: verify $AA
    ld  d, $AA
    ld  hl, VRAM_TEST_START
    call VDP_SetRead
    ld  bc, VRAM_TEST_END - VRAM_TEST_START + 1
.vram_r1:
    in  a, (VDP_DATA)
    cp  d
    jp  nz, .vram_fail
    inc hl
    dec bc
    ld  a, b
    or  c
    jr  nz, .vram_r1

    ; Pass 2: write $55
    ld  hl, VRAM_TEST_START
    call VDP_SetWrite
    ld  bc, VRAM_TEST_END - VRAM_TEST_START + 1
.vram_w2:
    ld  a, $55
    out (VDP_DATA), a
    dec bc
    ld  a, b
    or  c
    jr  nz, .vram_w2

    ; Pass 2: verify $55
    ld  d, $55
    ld  hl, VRAM_TEST_START
    call VDP_SetRead
    ld  bc, VRAM_TEST_END - VRAM_TEST_START + 1
.vram_r2:
    in  a, (VDP_DATA)
    cp  d
    jp  nz, .vram_fail
    inc hl
    dec bc
    ld  a, b
    or  c
    jr  nz, .vram_r2

.vram_pass:
    ld  hl, Str_Pass
    ld  de, VRAM_NAME + COLS * 7 + 22
    call PrintStr
    jr  .vram_done

.vram_fail:
    ; On entry: HL = failing VRAM address, D = expected, A = actual
    ld  e, a            ; save actual before A gets clobbered

    push hl
    push de
    ld  hl, Str_Fail
    ld  de, VRAM_NAME + COLS * 7 + 22
    call PrintStr
    pop  de
    pop  hl             ; HL = fail addr, D = expected, E = actual

    ; Detail line: "  $XXXX exp:$XX got:$XX"
    push de
    push hl
    ld  hl, VRAM_NAME + COLS * 8 + 2
    call VDP_SetWrite
    pop  hl
    pop  de

    ld  a, ' '
    out (VDP_DATA), a
    out (VDP_DATA), a
    ld  a, '$'
    out (VDP_DATA), a
    call PrintHex16     ; HL = fail address (preserved by PrintHex16)

    ld  a, ' '
    out (VDP_DATA), a
    ld  a, 'e'
    out (VDP_DATA), a
    ld  a, 'x'
    out (VDP_DATA), a
    ld  a, 'p'
    out (VDP_DATA), a
    ld  a, ':'
    out (VDP_DATA), a
    ld  a, '$'
    out (VDP_DATA), a
    ld  a, d
    call PrintHex8

    ld  a, ' '
    out (VDP_DATA), a
    ld  a, 'g'
    out (VDP_DATA), a
    ld  a, 'o'
    out (VDP_DATA), a
    ld  a, 't'
    out (VDP_DATA), a
    ld  a, ':'
    out (VDP_DATA), a
    ld  a, '$'
    out (VDP_DATA), a
    ld  a, e
    call PrintHex8

.vram_done:

    ; PSG register test (AY-3-8910).
    ; Only R0 is tested ($55 then $AA write+readback) — enough to show the
    ; chip is alive and the latch path ($A0/$A1/$A2) works. R7 (mixer) would
    ; add register-decode coverage, but its bits 7:6 set IOA/IOB direction;
    ; writing junk there breaks the later keyboard scan. Doing it safely needs
    ; read-modify-write, not worth it for v0.1.
    ld  hl, Str_PsgLabel
    ld  de, VRAM_NAME + COLS * 9 + 2
    call PrintStr

    ; Test R0: write $55, read back
    ld  a, 0
    out (PSG_ADDR), a
    ld  a, $55
    out (PSG_DATA), a
    ld  a, 0
    out (PSG_ADDR), a       ; re-latch R0 for read
    in  a, (PSG_READ)
    cp  $55
    ld  b, 0                ; B = register number
    ld  c, $55              ; C = expected
    ld  d, a                ; D = actual
    jp  nz, .psg_fail

    ; Test R0: write $AA, read back
    ld  a, 0
    out (PSG_ADDR), a
    ld  a, $AA
    out (PSG_DATA), a
    ld  a, 0
    out (PSG_ADDR), a
    in  a, (PSG_READ)
    cp  $AA
    ld  b, 0
    ld  c, $AA
    ld  d, a
    jp  nz, .psg_fail

    ; Restore R0 = 0
    ld  a, 0
    out (PSG_ADDR), a
    xor a
    out (PSG_DATA), a

.psg_pass:
    ld  hl, Str_Pass
    ld  de, VRAM_NAME + COLS * 9 + 22
    call PrintStr
    jr  .psg_done

.psg_fail:
    ; B = register number, C = expected, D = actual.
    ; The print routines don't touch B/C/D, so they survive across the prints.
    ld  hl, Str_Fail
    ld  de, VRAM_NAME + COLS * 9 + 22
    call PrintStr

    ; Detail line: "  R00 exp:$XX got:$XX"
    ld  hl, VRAM_NAME + COLS * 10 + 2
    call VDP_SetWrite

    ld  a, ' '
    out (VDP_DATA), a
    out (VDP_DATA), a
    ld  a, 'R'
    out (VDP_DATA), a
    ld  a, b
    call PrintHex8

    ld  a, ' '
    out (VDP_DATA), a
    ld  a, 'e'
    out (VDP_DATA), a
    ld  a, 'x'
    out (VDP_DATA), a
    ld  a, 'p'
    out (VDP_DATA), a
    ld  a, ':'
    out (VDP_DATA), a
    ld  a, '$'
    out (VDP_DATA), a
    ld  a, c
    call PrintHex8

    ld  a, ' '
    out (VDP_DATA), a
    ld  a, 'g'
    out (VDP_DATA), a
    ld  a, 'o'
    out (VDP_DATA), a
    ld  a, 't'
    out (VDP_DATA), a
    ld  a, ':'
    out (VDP_DATA), a
    ld  a, '$'
    out (VDP_DATA), a
    ld  a, d
    call PrintHex8

.psg_done:

    ; Slot register ($A8)
    ld  hl, Str_SlotLabel
    ld  de, VRAM_NAME + COLS * 12 + 2
    call PrintStr

    in  a, (SLOT_REG)
    ld  b, a                ; B = slot register value (preserved across all prints)

    ; Raw hex value at col 22
    ld  hl, VRAM_NAME + COLS * 12 + 22
    call VDP_SetWrite
    ld  a, '$'
    out (VDP_DATA), a
    ld  a, b
    call PrintHex8

    ; Decoded page map on row 13: "P0:x P1:x P2:x P3:x"
    ld  hl, VRAM_NAME + COLS * 13 + 2
    call VDP_SetWrite

    ld  a, 'P'
    out (VDP_DATA), a
    ld  a, '0'
    out (VDP_DATA), a
    ld  a, ':'
    out (VDP_DATA), a
    ld  a, b
    and $03                 ; bits 1:0 = page 0 slot
    add a, '0'
    out (VDP_DATA), a

    ld  a, ' '
    out (VDP_DATA), a
    ld  a, 'P'
    out (VDP_DATA), a
    ld  a, '1'
    out (VDP_DATA), a
    ld  a, ':'
    out (VDP_DATA), a
    ld  a, b
    rrca
    rrca
    and $03                 ; bits 3:2 = page 1 slot
    add a, '0'
    out (VDP_DATA), a

    ld  a, ' '
    out (VDP_DATA), a
    ld  a, 'P'
    out (VDP_DATA), a
    ld  a, '2'
    out (VDP_DATA), a
    ld  a, ':'
    out (VDP_DATA), a
    ld  a, b
    rrca
    rrca
    rrca
    rrca
    and $03                 ; bits 5:4 = page 2 slot
    add a, '0'
    out (VDP_DATA), a

    ld  a, ' '
    out (VDP_DATA), a
    ld  a, 'P'
    out (VDP_DATA), a
    ld  a, '3'
    out (VDP_DATA), a
    ld  a, ':'
    out (VDP_DATA), a
    ld  a, b
    rrca
    rrca
    rrca
    rrca
    rrca
    rrca
    and $03                 ; bits 7:6 = page 3 slot
    add a, '0'
    out (VDP_DATA), a

    ; Keyboard matrix
    ld  hl, Str_KbLabel
    ld  de, VRAM_NAME + COLS * 15 + 2
    call PrintStr

    ld  hl, VRAM_NAME + COLS * 16 + 2
    call VDP_SetWrite       ; VRAM position for raw row data

    ld  c, 0                ; C = matrix row counter (0-10)
.kb_loop:
    ; select row C in PPI port C bits 3:0, keep bits 7:4
    in  a, (KB_ROWSEL)
    and $F0
    or  c
    out (KB_ROWSEL), a

    in  a, (KB_COLRD)
    call PrintHex8          ; A = nibble char after this

    ld  a, c
    cp  10
    jr  z, .kb_last         ; no space after last row
    ld  a, ' '
    out (VDP_DATA), a
.kb_last:
    inc c
    ld  a, c
    cp  11
    jr  nz, .kb_loop

    ld  hl, Str_KbRead
    ld  de, VRAM_NAME + COLS * 15 + 22
    call PrintStr
.kb_done:

Halt:
    halt
    jr  Halt

Str_Banner:   DB "=== MSXDOC v0.1 ===", 0    ; 19 chars
Str_CpuLabel: DB "CPU ALU/REGS........", 0    ; 20 chars
Str_RamLabel: DB "RAM $C000-$FFFF.....", 0    ; 20 chars
Str_Pass:     DB "PASS", 0
Str_Fail:     DB "FAIL", 0
Str_VramLabel: DB "VRAM $1000-$3FFF....", 0  ; 20 chars
Str_PsgLabel:  DB "PSG AY-3-8910.......", 0  ; 20 chars
Str_SlotLabel: DB "SLOT REGISTER $A8...", 0  ; 20 chars
Str_KbLabel:   DB "KB MATRIX $A9/$AA...", 0  ; 20 chars
Str_KbRead:    DB "READ", 0

; VDP_WriteReg: write A to VDP register E (0..7). Clobbers A. Byte flip-flop
; must already be synced.
VDP_WriteReg:
    out (VDP_CTRL), a
    ld  a, e
    or  $80
    out (VDP_CTRL), a
    ret

; LoadFont: write 96 x 8 bytes of row-major glyph data to the pattern table
; starting at ASCII $20 (VRAM $0800 + $20*8 = $0900). Font comes from the
; embedded font.bin at the bottom of the file.
LoadFont:
    ld  hl, VRAM_PTRN + $20 * 8
    call VDP_SetWrite
    ld  hl, Font
    ld  bc, 96 * 8
.loop:
    ld  a, (hl)
    out (VDP_DATA), a
    inc hl
    dec bc
    ld  a, b
    or  c
    jr  nz, .loop
    ret

; VDP_SetWrite: set VRAM write address from HL.
VDP_SetWrite:
    ld  a, l
    out (VDP_CTRL), a
    ld  a, h
    or  $40
    out (VDP_CTRL), a
    ret

; VDP_SetRead: set VRAM read address from HL.
VDP_SetRead:
    ld  a, l
    out (VDP_CTRL), a
    ld  a, h
    and $3F
    out (VDP_CTRL), a
    ret

; ClearScreen: fill name table (40x24) with spaces.
ClearScreen:
    ld  hl, VRAM_NAME
    call VDP_SetWrite
    ld  bc, COLS * 24
.loop:
    ld  a, ' '
    out (VDP_DATA), a
    dec bc
    ld  a, b
    or  c
    jr  nz, .loop
    ret

; PrintStr: write null-terminated string to VRAM.
; HL = ROM string pointer, DE = VRAM destination.
PrintStr:
    push hl
    ld  h, d
    ld  l, e
    call VDP_SetWrite
    pop hl
.loop:
    ld  a, (hl)
    or  a
    ret z
    out (VDP_DATA), a
    inc hl
    jr  .loop

; PrintHex16: print HL as 4 hex chars at the current VRAM position. Preserves HL.
PrintHex16:
    push hl
    ld  a, h
    call PrintHex8
    ld  a, l
    call PrintHex8
    pop  hl
    ret

; PrintHex8: print A as 2 hex chars at the current VRAM position.
PrintHex8:
    push af
    rrca
    rrca
    rrca
    rrca
    call PrintNibble    ; high nibble
    pop  af
    ; fall through to PrintNibble for the low nibble

; PrintNibble: print low nibble of A as one hex char.
PrintNibble:
    and  $0F
    add  a, '0'
    cp   '9' + 1
    jr   c, .ok
    add  a, 7           ; bump to 'A'-'F'  ('A'-'0'-10 = 7)
.ok:
    out  (VDP_DATA), a
    ret

; TestCPU: Z80 ALU and register tests, no RAM required.
; Returns A=0 on pass, A=test number on first failure.
TestCPU:
    ; 1. 8-bit addition
    ld  a, $3C
    add a, $3C          ; $78
    cp  $78
    ld  a, 1
    ret nz

    ; 2. subtraction goes negative, so sign flag (M) should be set
    ld  a, $50
    sub $51             ; $FF, negative
    jp  p, .fail        ; positive means broken

    ; 3. Zero flag
    ld  a, $42
    sub $42
    ld  a, 3
    ret nz

    ; 4. AND
    ld  a, $F0
    and $0F             ; $00
    ld  a, 4
    ret nz

    ; 5. OR
    ld  a, $F0
    or  $0F             ; $FF
    cp  $FF
    ld  a, 5
    ret nz

    ; 6. XOR
    ld  a, $FF
    xor $AA             ; $55
    cp  $55
    ld  a, 6
    ret nz

    ; 7. 16-bit INC across byte boundary
    ld  hl, $12FF
    inc hl              ; $1300
    ld  a, h
    cp  $13
    ld  a, 7
    ret nz
    ld  a, l
    or  a
    ld  a, 7
    ret nz

    ; 8. CPL
    ld  a, $A5
    cpl                 ; $5A
    cp  $5A
    ld  a, 8
    ret nz

    ; 9. RLCA: rotate left, bit 7 into carry
    ld  a, $80
    rlca                ; A=$01, CF=1
    cp  $01
    ld  a, 9
    ret nz

    ; 10. RLA: rotate left through carry
    scf
    ld  a, $40
    rla                 ; A=$81
    cp  $81
    ld  a, 10
    ret nz

    ; 11. EX AF,AF'
    ld  a, $42
    ex  af, af'
    ld  a, $FF
    ex  af, af'
    cp  $42
    ld  a, 11
    ret nz

    ; 12. EXX
    ld  bc, $1234
    exx
    ld  bc, $ABCD
    exx
    ld  a, b
    cp  $12
    ld  a, 12
    ret nz
    ld  a, c
    cp  $34
    ld  a, 12
    ret nz

    xor a
    ret

.fail:
    ld  a, 1
    ret

; Embedded font: 96 x 8 bytes (768), row-major 6x8.
; Generated by scripts/gen_msx_font.py from src/firmware/oled.c font5x7[].
Font:
    INCBIN "font.bin"

    SAVEBIN "diag.rom", $4000, $4000

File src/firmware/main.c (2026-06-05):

#include "pico/stdlib.h"
#include "pico/multicore.h"
#include "pico/bootrom.h"
#include "hardware/gpio.h"
#include "hardware/irq.h"
#include "hardware/adc.h"
#include "hardware/clocks.h"
#include "hardware/watchdog.h"
#include <stdio.h>

#include "ipc.h"
#include "msx_runtime.h"
#include "bus_probe.h"
#include "boot_diag.h"
#include "oled.h"
#include "usb_serial.h"
#include "adc_rails.h"
#include "buttons.h"
#include "ui.h"
#include "cmd_dispatch.h"

#define GP_LED       38

static usb_out_ring_t  usb_out;
static cmd_ring_t      cmd_ring;
static rail_snapshot_t rail_snap;

static void __not_in_flash_func(core1_dashboard_loop)(void) {
    /* During a boot-diagnostic round, drain the capture rings — drain-only, no
     * blocking, since blocking here loses events. Otherwise run the lightweight
     * passive dashboard sampler. boot_diag_tick() on Core 0 owns the
     * active/inactive switch. */
    while (true) {
        if (boot_diag_capture_active())
            boot_diag_core1_drain_step();
        else
            bus_probe_sample_once();
    }
}

static void __not_in_flash_func(core1_entry)(void) {
    multicore_fifo_pop_blocking();   /* go signal from Core 0 */
    core1_dashboard_loop();
}

int main(void) {
    /* The first-proto POR network (R1=10k, C6=100nF, τ=1ms) has marginal hold
     * time; on cold power-up the chip sometimes comes out of reset glitched and
     * never reaches the main loop. The watchdog auto-resets after 5 s if the
     * loop (which feeds it every iteration) isn't running. Pause-on-debug is
     * true so SWD stepping doesn't trip resets during dev. */
    watchdog_enable(5000, true);

    /* LED on — first GPIO write (FW-006). */
    gpio_init(GP_LED);
    gpio_set_dir(GP_LED, GPIO_OUT);
    gpio_put(GP_LED, 1);

    set_sys_clock_khz(150000, true);   /* must be first (FW-007) */

    /* OLED before the power check (FW-009). */
    oled_init();
    oled_set_state(DISP_BOOT);

    usb_serial_init();

    ui_init();

    /* Rails are sampled and classified by the Core 0 monitor; no hard halt
     * here, so USB-only bring-up (all MSX rails legitimately absent) still
     * reaches the main loop and TinyUSB. */
    adc_rails_init();
    adc_rails_sample();

    /* Init IPC ring spin-locks before anything that takes a ring pointer
     * (msx_runtime_serve_detect_init, Core 1 launch). Per FW-011. */
    usb_out.lock  = spin_lock_init(spin_lock_claim_unused(true));
    cmd_ring.lock = spin_lock_init(spin_lock_claim_unused(true));

    /* cart_serve is autonomous PIO+DMA with no ISR, so only USB and I2C need a
     * priority set. */
    irq_set_priority(USBCTRL_IRQ,  2);
    irq_set_priority(I2C0_IRQ,     2);

    /* Bring the bus up read-only: the cart watches, never drives. The MSX boots
     * its own BASIC and we don't park /RESET. */
    msx_runtime_passive_init();

    /* Clock-frequency counter (PWM7B on GP31). Must run before Core 1 starts
     * sampling. */
    bus_probe_init();

    buttons_init();
    /* SW2 (UP) + SW3 (DOWN) held >= 500 ms resets the MSX. Suppresses short-press
     * UP/DOWN events during combo intent so navigation doesn't flicker. */
    buttons_set_combo(BTN_UP, BTN_DOWN, 500);

    multicore_launch_core1(core1_entry);
    multicore_fifo_push_blocking(1);

    oled_set_state(DISP_MONITORING);

    uint32_t last_rail_update_ms = 0;
    uint32_t last_btn_poll_ms    = 0;
    uint8_t  fault_count         = 0;   /* consecutive rail-FAIL polls; debounces MSX PSU soft-start */
    uint32_t        last_oled_ms = 0;

    for (;;) {
        watchdog_update();

        uint32_t now_ms = to_ms_since_boot(get_absolute_time());

        /* tud_task + drain output ring + buffer RX commands. */
        usb_serial_task(&usb_out, &cmd_ring);

        /* Advance any in-flight boot-diagnostic round. Non-blocking except its
         * 100 ms /RESET pulse, which fits the 5 s watchdog budget. */
        boot_diag_tick(now_ms);

        adc_rails_sample();   /* one rail per iteration, round-robin */

        /* Only treat a FAIL as a power fault when the MSX is actually powered
         * (at least one positive rail not ABSENT). On USB-only every rail is
         * ABSENT, so a stray -12 V FAIL from PCB leakage shouldn't blink the
         * fault page; MONITORING and the boot observer cover the "MSX off/dead"
         * case.
         *
         * The MSX PSU ±12 V soft-start takes 50-500 ms and the cart MCU boots
         * faster, so the first rail check can land mid-ramp and read FAIL on
         * still-rising rails. Require 4 consecutive 500 ms FAIL polls (2 s)
         * before tripping POWER_FAULT, and auto-clear once the condition lifts
         * so a transient fault doesn't latch the display. */
        if (now_ms - last_rail_update_ms >= 500) {
            last_rail_update_ms = now_ms;
            adc_rails_snapshot(&rail_snap);
            bool msx_present = (rail_snap.status_5v != 3) ||
                               (rail_snap.status_12v != 3);
            bool any_fail    = (rail_snap.status_5v   == 2) ||
                               (rail_snap.status_12v  == 2) ||
                               (rail_snap.status_m12v == 2);
            const uint8_t FAULT_DEBOUNCE = 4;
            if (msx_present && any_fail) {
                if (fault_count < FAULT_DEBOUNCE) fault_count++;
                if (fault_count >= FAULT_DEBOUNCE) {
                    ui_notify_power_fault(true);
                }
            } else {
                fault_count = 0;
                ui_notify_power_fault(false);
            }

        }

        if (now_ms - last_btn_poll_ms >= 1) {
            last_btn_poll_ms = now_ms;
            btn_event_t btn = buttons_poll();
            /* Any button dismisses the MSX_HEALTH page back to MONITORING. */
            if (btn != BTN_NONE && oled_get_state() == DISP_MSX_HEALTH) {
                oled_set_state(DISP_MONITORING);
            } else {
                ui_handle_btn(btn);
            }
            if (buttons_combo_check()) msx_reset_pulse();
        }

        char cmd_buf[CMD_LINE_LEN];
        if (usb_serial_get_cmd(&cmd_ring, cmd_buf, sizeof(cmd_buf))) {
            parsed_cmd_t cmd = usb_serial_parse_cmd(cmd_buf);
            cmd_dispatch(&cmd, &usb_out, &rail_snap);
        }

        /* OLED refresh every 100 ms: pull the latest probe snapshot into the
         * UI and render. */
        if (now_ms - last_oled_ms >= 100) {
            last_oled_ms = now_ms;
            bus_probe_snapshot_t probe;
            bus_probe_get(&probe);
            ui_set_probe(&probe);
            oled_refresh(&rail_snap, NULL, 0, 0, false);
        }
    }
}
